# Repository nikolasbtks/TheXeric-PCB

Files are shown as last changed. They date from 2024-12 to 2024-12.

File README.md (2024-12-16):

# TheXeric-PCB

## Description

This project demonstrates a custom 2-layer PCB containing the ATmega-4809 microcontroller. This board can be used for embedded development applications using multiple peripherals.

## Components

1. Microcontroller: ATmega4809
   - 6 KB SRAM and 48 MB Flash
   - 20 MHz clock speed 
   
3. USB Connectivity:
   - USB Type-C for data and power 
   - USBLC6-2SC6 for ESD protection

4. Power Supply: LM3670MF-3.3 
   - Voltage regulator for stable 3.3V output
  
5. Headers:
   - UPDI header for debugging
   - GPIO, I2C, SPI and USART headers for external connections

6. Memory: AT24CS32-STUM
   - 32 Kbit of EEPROM storage
   - Non-volatile memory storage expansion

8. Sensor: TC1047xNB
   - Analog voltage output, propotional to temperature

## Disclaimer

This project is currently in **testing phase**. The provided documentation is shared for prototyping and learning purposes. If you choose to manufacture and use the board, please proceed with care, as it has not yet been fully validated.

## Schematic and PCB Design

The board was designed using KiCad. Files from the PCB design can be found in the **hardware** folder for board manufacture. This folder includes:

- PCB Schematic 
- PCB Layout
- Gerber files
- Assembly files

Below is a 3D render of the PCB design:
TheXeric

## How to Use

1. Power the board
   - Use a USB Type-C cable to power the board.
     
2. Microcontroller Programming:
   - Use Arduino IDE or any other platform to program the microcontroller.
   - Use a debugger with a UPDI header.

3. Peripheral Access
   - Use the GPIO, I2C, SPI and USART headers to connect peripherals.

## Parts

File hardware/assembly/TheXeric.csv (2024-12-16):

Reference | Value | Datasheet | Footprint | Qty | DNP
C1,C4,C7,C12 | 100nF | ~ | Capacitor_SMD:C_0402_1005Metric | 4
C2,C3 | 22pF | ~ | Capacitor_SMD:C_0402_1005Metric | 2
C5,C8 | 4.7μF | ~ | Capacitor_SMD:C_0603_1608Metric | 2
C6,L1 | 10μF | ~ | -- διάφορες τιμές -- | 2
C9 | 10nF | ~ | Capacitor_SMD:C_0402_1005Metric | 1
C10,C11 | 1μF | ~ | Capacitor_SMD:C_0603_1608Metric | 2
D1,D2,D3,D4,D6 | LED | ~ | LED_SMD:LED_0603_1608Metric | 5
F1 | 500mA | ~ | Fuse:Fuse_0402_1005Metric | 1
FB1 | FerriteBead | ~ | Inductor_SMD:L_0603_1608Metric | 1
J1 | USB_C_Receptacle_USB2.0_16P | https://www.usb.org/sites/default/files/documents/usb_type-c.zip | Connector_USB:USB_C_Receptacle_GCT_USB4105-xx-A_16P_TopMnt_Horizontal | 1
J2,J3,J5,J6,J7,J8 | Conn_01x04_Pin | ~ | Connector_PinHeader_2.54mm:PinHeader_1x04_P2.54mm_Vertical | 6
J4,J9 | Conn_01x03_Pin | ~ | Connector_PinHeader_2.54mm:PinHeader_1x03_P2.54mm_Vertical | 2
R1,R2 | 10k | ~ | Resistor_SMD:R_0402_1005Metric | 2
R3,R4,R5,R6,R8 | 100R | ~ | Resistor_SMD:R_0603_1608Metric | 5
R7,R9 | 5.1k | ~ | Resistor_SMD:R_0402_1005Metric | 2
R10,R11 | 4.7k | ~ | Resistor_SMD:R_0402_1005Metric | 2
R12,R13,R14,R15 | 1k5 | ~ | Resistor_SMD:R_0402_1005Metric | 4
SW1 | SW_SPDT_312 | ~ | Button_Switch_SMD:SW_SPDT_PCM12 | 1
SW2,SW3 | SW_Push | ~ | Button_Switch_SMD:SW_SPST_B3U-1000P | 2
U1 | USBLC6-2SC6 | https://www.st.com/resource/en/datasheet/usblc6-2.pdf | Package_TO_SOT_SMD:SOT-23-6 | 1
U2 | ATmega4809-A | http://ww1.microchip.com/downloads/en/DeviceDoc/40002016A.pdf | Package_QFP:TQFP-48_7x7mm_P0.5mm | 1
U3 | TC1047xNB | http://ww1.microchip.com/downloads/en/DeviceDoc/21498D.pdf | Package_TO_SOT_SMD:SOT-23 | 1
U4 | AT24CS32-STUM | http://ww1.microchip.com/downloads/en/DeviceDoc/Atmel-8869-SEEPROM-AT24CS32-Datasheet.pdf | Package_TO_SOT_SMD:SOT-23-5 | 1
U5 | MCP2210x-MQ | https://ww1.microchip.com/downloads/en/DeviceDoc/22288A.pdf | Package_DFN_QFN:QFN-20-1EP_5x5mm_P0.65mm_EP3.35x3.35mm | 1
U6 | LM3670MF | http://www.ti.com/lit/ds/symlink/lm3670.pdf | Package_TO_SOT_SMD:TSOT-23-5 | 1
Y1 | 12MHz | ~ | Crystal:Crystal_SMD_3215-2Pin_3.2x1.5mm | 1

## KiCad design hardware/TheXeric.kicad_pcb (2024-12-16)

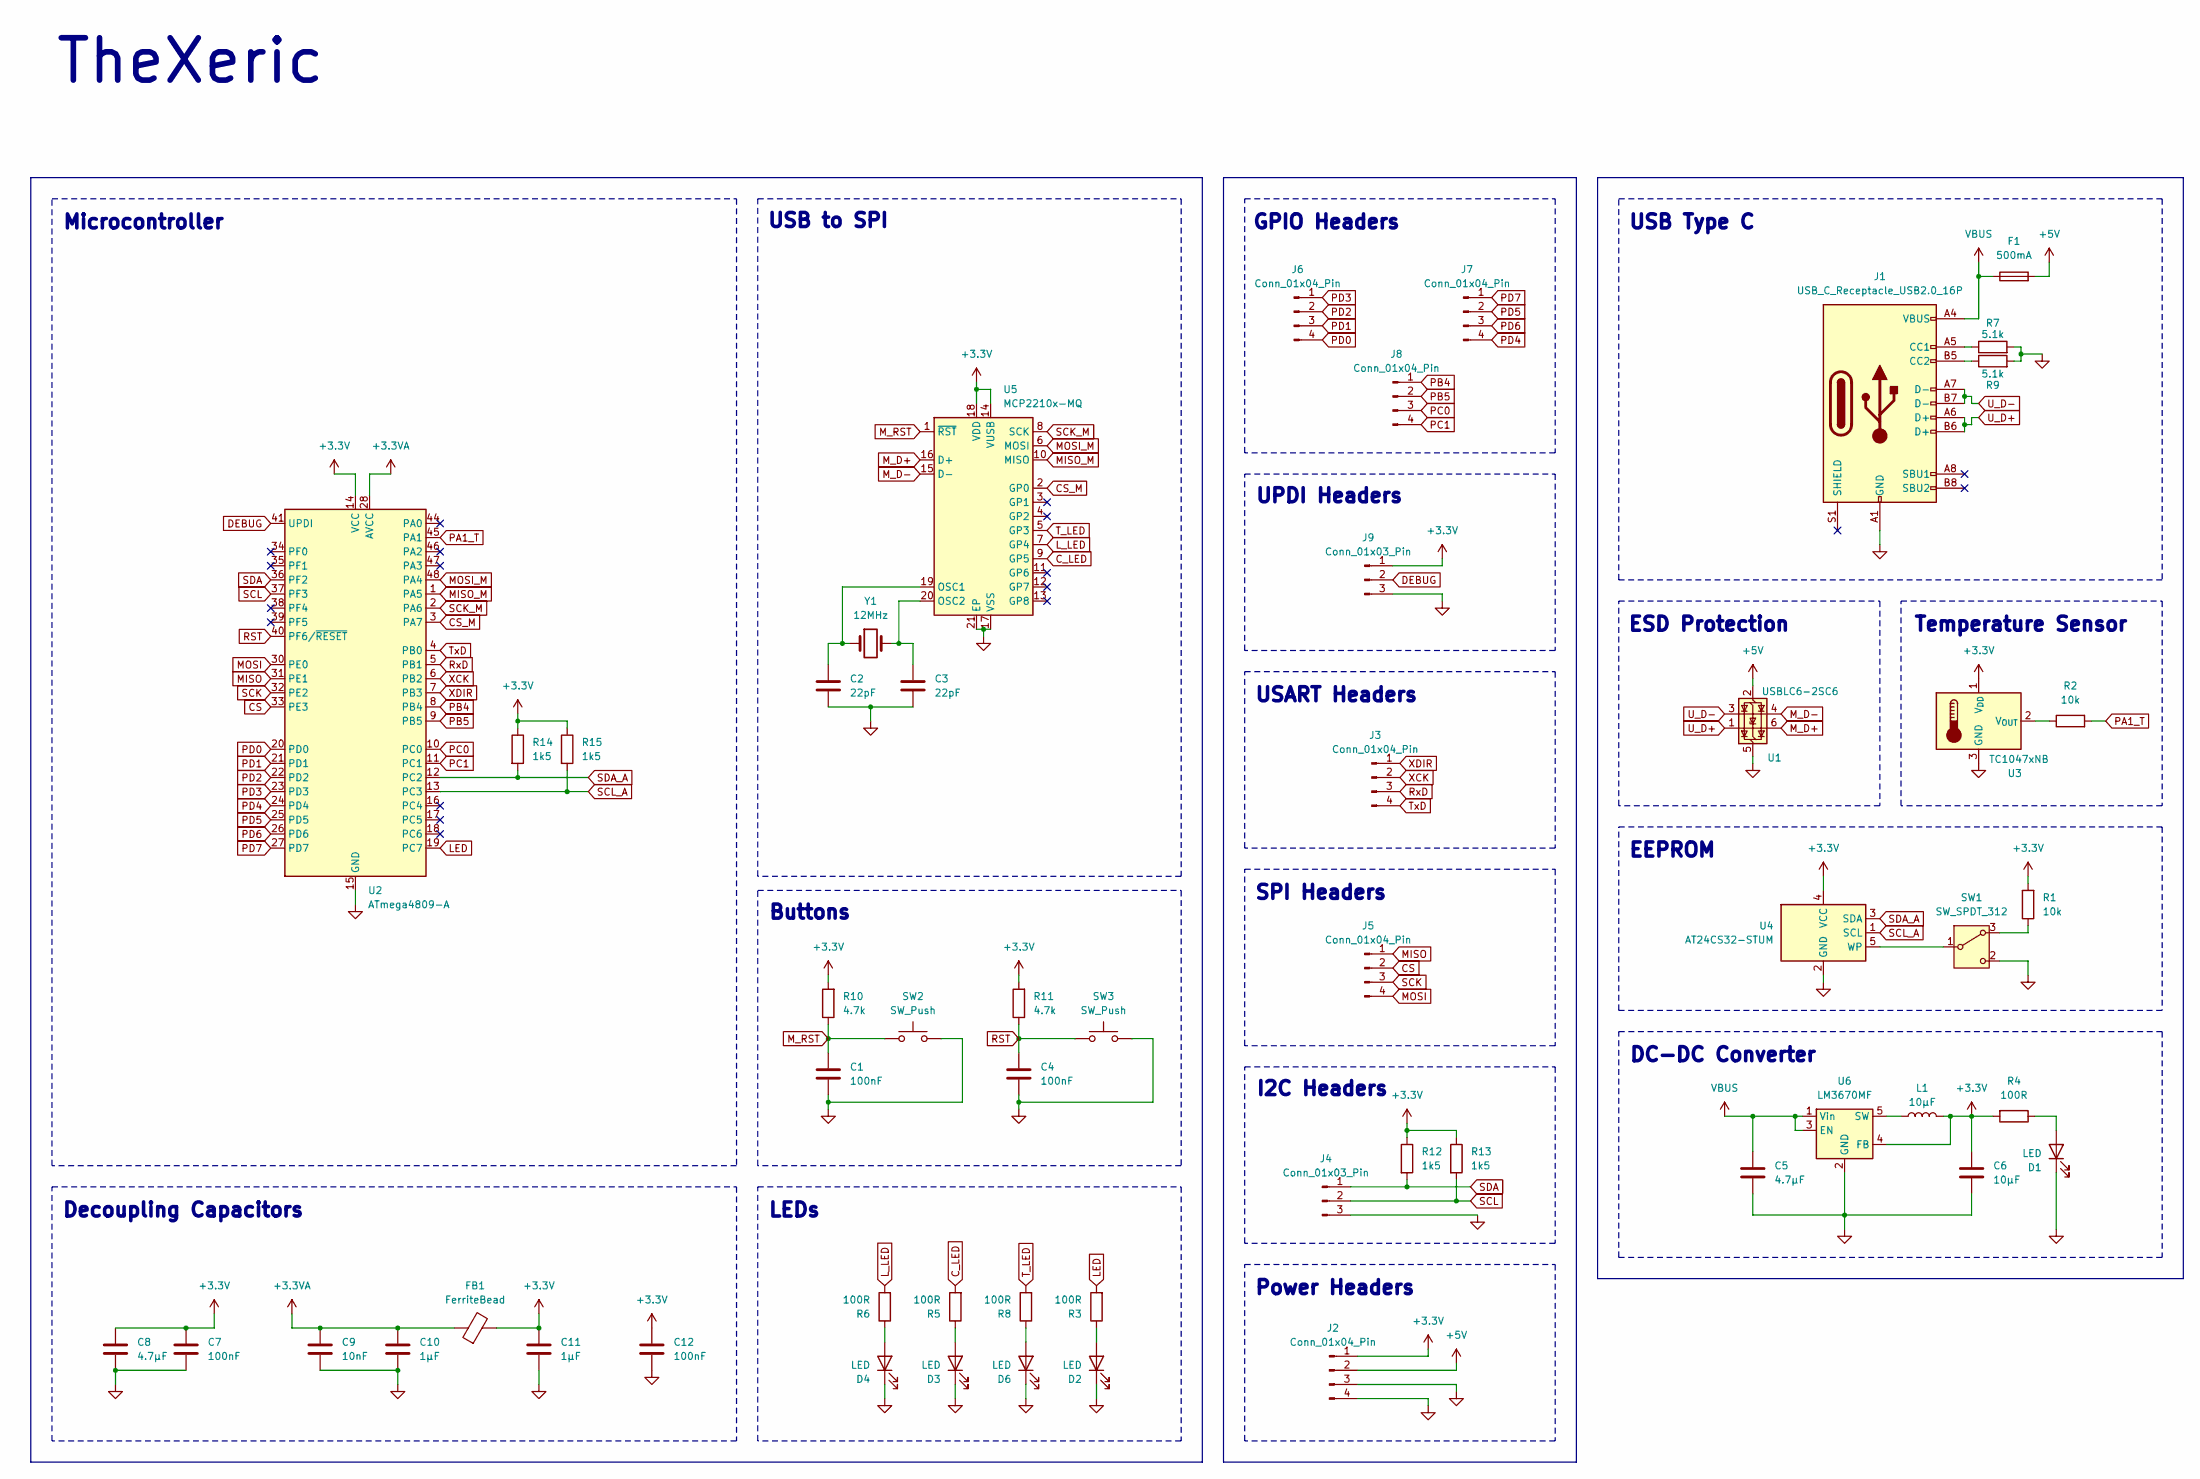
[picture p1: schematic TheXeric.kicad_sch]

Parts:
C1, C4, C7, C12: 100nF; C_0402_1005Metric
C2, C3: 22pF; C_0402_1005Metric
C5, C8: 4.7μF; C_0603_1608Metric
C6: 10μF; C_0603_1608Metric
C9: 10nF; C_0402_1005Metric
C10, C11: 1μF; C_0603_1608Metric
D1, D2, D3, D4, D6: LED; LED_0603_1608Metric
F1: 500mA; Fuse_0402_1005Metric
FB1: FerriteBead; L_0603_1608Metric
J1: USB_C_Receptacle_USB2.0_16P; USB_C_Receptacle_GCT_USB4105-xx-A_16P_TopMnt_Horizontal
J2, J3, J5, J6, J7, J8: Conn_01x04_Pin; PinHeader_1x04_P2.54mm_Vertical
J4, J9: Conn_01x03_Pin; PinHeader_1x03_P2.54mm_Vertical
L1: 10μF; L_0603_1608Metric
R1, R2: 10k; R_0402_1005Metric
R3, R4, R5, R6, R8: 100R; R_0603_1608Metric
R7, R9: 5.1k; R_0402_1005Metric
R10, R11: 4.7k; R_0402_1005Metric
R12, R13, R14, R15: 1k5; R_0402_1005Metric
SW1: SW_SPDT_312; SW_SPDT_PCM12
SW2, SW3: SW_Push; SW_SPST_B3U-1000P
U1: USBLC6-2SC6; SOT-23-6
U2: ATmega4809-A; TQFP-48_7x7mm_P0.5mm
U3: TC1047xNB; SOT-23
U4: AT24CS32-STUM; SOT-23-5
U5: MCP2210x-MQ; QFN-20-1EP_5x5mm_P0.65mm_EP3.35x3.35mm
U6: LM3670MF; TSOT-23-5
Y1: 12MHz; Crystal_SMD_3215-2Pin_3.2x1.5mm

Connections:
+3.3V: C6.1, C7.1, C8.1, C11.1, C12.1, FB1.2, J2.1, J9.1, L1.2, R1.2, R4.2, R10.2, R11.2, R12.1, R13.1, R14.1, R15.1, U2.14 (VCC), U2.42 (VCC), U3.1 (V_{DD}), U4.4 (VCC), U5.14 (VUSB), U5.18 (VDD), U6.4 (FB)
+3.3VA: C9.1, C10.1, FB1.1, U2.28 (AVCC)
+5V: F1.2, J2.2, U1.2 (GND)
CS: J5.2, U2.33 (PE3)
CS_M: U2.3 (PA7), U5.2 (GP0)
C_LED: R5.2, U5.9 (GP5)
DEBUG: J9.2, U2.41 (UPDI)
GND: C1.2, C2.2, C3.2, C4.2, C5.2, C6.2, C7.2, C8.2, C9.2, C10.2, C11.2, C12.2, D1.1 (K), D2.1 (K), D3.1 (K), D4.1 (K), D6.1 (K), J1.A1 (GND), J1.A12 (GND), J1.B1 (GND), J1.B12 (GND), J2.3, J2.4, J4.3, J9.3, R7.2, R9.2, SW1.2 (C), SW2.2, SW3.2, U1.5 (VBUS), U2.15 (GND), U2.29 (GND), U2.43 (GND), U3.3 (GND), U4.2 (GND), U5.17 (VSS), U5.21 (EP), U6.2 (GND)
LED: R3.2, U2.19 (PC7)
L_LED: R6.2, U5.7 (GP4)
MISO: J5.1, U2.31 (PE1)
MISO_M: U2.1 (PA5), U5.10 (MISO)
MOSI: J5.4, U2.30 (PE0)
MOSI_M: U2.48 (PA4), U5.6 (MOSI)
M_D+: U1.6 (I/O1), U5.16 (D+)
M_D-: U1.4 (I/O2), U5.15 (D-)
M_RST: C1.1, R10.1, SW2.1, U5.1 (~RST)
unnamed: D1.2 (A), R4.1
unnamed: D2.2 (A), R3.1
unnamed: D3.2 (A), R5.1
unnamed: D4.2 (A), R6.1
unnamed: D6.2 (A), R8.1
unnamed: J1.A5 (CC1), R7.1
unnamed: J1.B5 (CC2), R9.1
unnamed: R1.1, SW1.3 (A)
unnamed: SW1.1 (B), U4.5 (WP)
unnamed: R2.1, U3.2 (V_{OUT})
unnamed: C2.1, U5.19 (OSC1), Y1.1
unnamed: C3.1, U5.20 (OSC2), Y1.2
unnamed: L1.1, U6.5 (SW)
PA1_T: R2.2, U2.45 (PA1)
PB4: J8.1, U2.8 (PB4)
PB5: J8.2, U2.9 (PB5)
PC0: J8.3, U2.10 (PC0)
PC1: J8.4, U2.11 (PC1)
PD0: J6.4, U2.20 (PD0)
PD1: J6.3, U2.21 (PD1)
PD2: J6.2, U2.22 (PD2)
PD3: J6.1, U2.23 (PD3)
PD4: J7.4, U2.24 (PD4)
PD5: J7.2, U2.25 (PD5)
PD6: J7.3, U2.26 (PD6)
PD7: J7.1, U2.27 (PD7)
RST: C4.1, R11.1, SW3.1, U2.40 (PF6/~RESET)
RxD: J3.3, U2.5 (PB1)
SCK: J5.3, U2.32 (PE2)
SCK_M: U2.2 (PA6), U5.8 (SCK)
SCL: J4.2, R13.2, U2.37 (PF3)
SCL_A: R15.2, U2.13 (PC3), U4.1 (SCL)
SDA: J4.1, R12.2, U2.36 (PF2)
SDA_A: R14.2, U2.12 (PC2), U4.3 (SDA)
T_LED: R8.2, U5.5 (GP3)
TxD: J3.4, U2.4 (PB0)
U_D+: J1.A6 (D+), J1.B6 (D+), U1.1 (I/O1)
U_D-: J1.A7 (D-), J1.B7 (D-), U1.3 (I/O2)
VBUS: C5.1, F1.1, J1.A4 (VBUS), J1.A9 (VBUS), J1.B4 (VBUS), J1.B9 (VBUS), U6.1 (Vin), U6.3 (EN)
XCK: J3.2, U2.6 (PB2)
XDIR: J3.1, U2.7 (PB3)

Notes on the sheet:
Microcontroller
EEPROM
USART Headers
LEDs
USB Type C
Power Headers
Buttons
UPDI Headers
GPIO Headers
TheXeric
I2C Headers
USB to SPI
SPI Headers
DC-DC Converter
Decoupling Capacitors
ESD Protection
Temperature Sensor

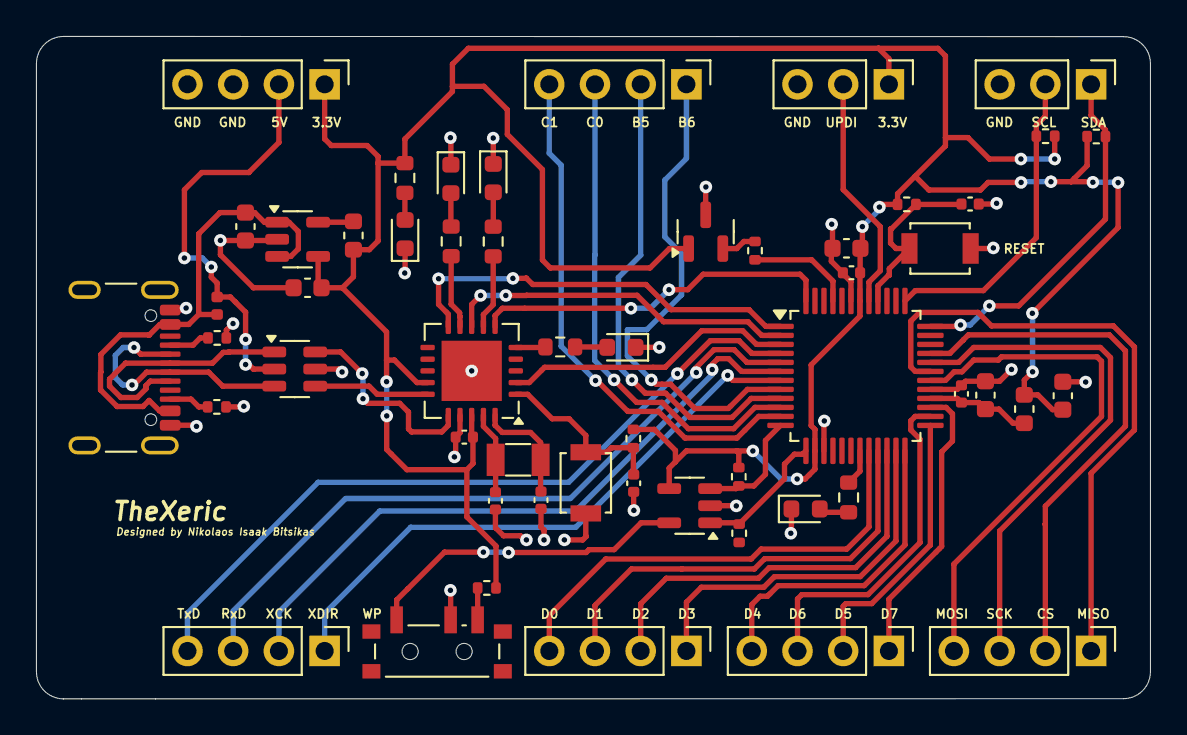
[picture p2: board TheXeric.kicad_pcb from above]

Board: 2 copper layers, 61.9 x 36.8 mm, 54 parts (0 on the bottom side), 58 nets.
